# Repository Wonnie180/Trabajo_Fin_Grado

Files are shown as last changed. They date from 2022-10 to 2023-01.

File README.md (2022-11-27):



# Trabajo_Fin_Grado
Repositorio para el TFG UPNA (2022/2023)

# Requisitos Previos
## Hardware
### Para cada robot
- ESP32
- 2x Motores
- Batería
- 74HC595N
- L293D
  
###
## Software
## Windows
### Programas necesarios
- [Visual Studio Community 2019](https://visualstudio.microsoft.com/es/vs/older-downloads/)
- [Cuda ToolKit](https://developer.nvidia.com/cuda-toolkit)
- [CMake](https://cmake.org/download/)
- [Anaconda3](https://www.anaconda.com/products/distribution)
- [Código fuente de OpenCV](https://github.com/opencv/opencv)
- [Código fuente de OpenCV Contrib](https://github.com/opencv/opencv_contrib) (Misma versión que OpenCV)

### Configuraciones
#### Entorno Python
Modulos a instalar:
> pip install pybluez2 ndarray-listener-2.0.1 aioconsole

#### Compilar OpenCV con soporte para CUDA (GPU)
Importante:
Durante el tutorial se va a asumir que el directorio donde se va a trabajar es la siguiente:
>C:/Users/Usuario/Escritorio/OpenCV-GPU

1.  Crea una carpeta donde se almacenara el código fuente de OpenCV
Por Ejemplo: 
>C:/Users/Usuario/Escritorio/OpenCV-GPU

2.  Descomprime tanto el código fuente de OpenCV como OpenCV Contrib en dicha carpeta.
Deberían aparecer dos nuevas carpetas de forma que la estructura quede de la siguiente forma:
>C:/Users/Usuario/Escritorio/OpenCV-GPU/opencv-4.6.0\
>C:/Users/Usuario/Escritorio/OpenCV-GPU/opencv_contrib-4.6.0

3.  Crea una carpeta llamada build en el directorio de trabajo.
>C:/Users/Usuario/Escritorio/OpenCV-GPU

4.  Abre CMake
    1. En el apartado "Where is the source code:" introduce la carpeta donde se ha descomprimido el código fuente de OpenCV  
    > C:/Users/Usuario/Escritorio/OpenCV-GPU/opencv-4.6.0

    2. En el apartado "Where to build the binaries:", introduce la carpeta build creada en el paso anterior .
    >C:/Users/Usuario/Escritorio/OpenCV-GPU/build

    3. Dale al botón __Configure__
        1. En el primer apartado selecciona Visual Studio 17 2022
        2. En el segundo apartado selecciona x64
        3. Deja el resto como viene y dale a __Finish__

    4. Ahora busca las siguientes opciones y marcalas:
        * WITH_CUDA
        * ENABLE_FAST_MATH
        * BUILD_opencv_world
        * CUDA_FAST_MATH
    
    5. Busca __OPENCV_EXTRA_MODULES_PATH__ e introduce la carpeta modules que esta en la carpeta de OpenCV Contrib
    >C:/Users/Usuario/Escritorio/opencv_contrib-4.6.0/modules

    6. Vuelve a pinchar en __Configure__. Si no da ningún error, procede al siguiente punto.

    7. Ahora busca __CUDA_ARCH_BIN__. Aquí hay que seleccionar la Arquitectura de tu gráfica NVIDIA. Para ello tendrás que ir a la [Wikipedia](https://en.wikipedia.org/wiki/CUDA) y buscar tu gráfica. Tras encontrarla en la tabla, Introduce la versión de la primera columna (6.1 en el caso de una GTX 1080ti por ejemplo) en el parametro de CMake.     
    8. Busca el parametro __CMAKE_CONFIGURATION_TYPES__ y deja solo "Release".
    9. Por último, presiona el botón __Generate__.

5. A continuación, abre una ventana de linea de comandos (cmd o Powershell) y ejecuta el siguiente comando:
> & 'C:\Program Files\CMake\bin\cmake.exe' --build "C:/Users/Usuario/Escritorio/OpenCV-GPU/build" --target INSTALL --config Release

6. Cuando el proceso de compilación termine, en la misma terminal ejecuta __Python__ y ejecuta el siguiente código:
```
import cv2
cv2.cuda.getCudaEnabledDeviceCount()
```
&nbsp;&nbsp;&nbsp;&nbsp;&nbsp;&nbsp;
Si el resultado es un número mayor que 0, ya está todo listo para utilizar CUDA con OpenCV.  

#### Linux
TBD

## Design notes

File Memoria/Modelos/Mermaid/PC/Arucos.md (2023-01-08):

```mermaid
classDiagram
    %% -- Arucos
    IAruco <|-- Aruco
    Aruco <|-- Aruco_Drawable
    Runnable <|-- Aruco_Drawable
    Aruco_Drawable *-- IVideoSource 
    Aruco_Drawable *-- CV2ImShow_Drawable 

    IAruco: -int current_id
    IAruco: -any dictionary
    IAruco: -any detector_parameters
    IAruco: -any corners
    IAruco: -any ids
    IAruco: -any rejected

    IAruco: +Get_Current_Id() void
    IAruco: +Generate_new_Id(int size) any
    IAruco: +Detect_Aruco(Frame frame) void
    IAruco: +Get_Position_Of_Aruco(int id) any

    class Aruco{
       +Aruco(any dictionary, any detector_parameters) Aruco
    }

    class Aruco_Drawable{
        -IVideoSource video_source
        -CV2ImShow_Drawable video_playback
        -int frame_rate
        -int sleep_time

        +Aruco_Drawable(any dictionary, any detector_parameters, IVideoSource video_source, CV2ImShow_Drawable video_playback) Aruco_Drawable
        +Draw_Detected_Aruco() void
    }
```

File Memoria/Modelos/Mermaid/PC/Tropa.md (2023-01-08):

```mermaid
classDiagram
    %% -- Tropas
    ITropa <|-- Tropa
    ITropa <|-- FakeTropa
    ITropa *-- ICommunication
    ITropa *-- IPosition
    ITropa *-- Color
    
    ITropa: +int id
    ITropa: +ICommunication communication
    ITropa: +Color color
    ITropa: +IPosition position

    ITropa: +Move_Forward()
    ITropa: +Move_Backwards() void
    ITropa: +Turn_Left() void
    ITropa: +Turn_Right() void
    ITropa: +Set_Color(Color color) void
    class FakeTropa{
        -int time_delay
        -int[][][] matrix
        -int[][][] footprint
        +int degree_step
        +int distance_step

        +FakeTropa(int id, ICommunication communication, Color color, int[][][] matrix, int[][][] footprint, Position_2D position) FakeTropa
        -Do_Turn(int angle_direction, bool forward) void
        -Update_Matrix(int pos_x, int pos_y) void
        -Get_Movement_Parameters(int angle, int degree_of_movement) int[]
        -isValidFootPrint(int[][][] matrix, int[][][]footprint) bool
    }
    class Tropa{
        +Tropa(int id, ICommunication communication, Color color) Tropa
    }
```

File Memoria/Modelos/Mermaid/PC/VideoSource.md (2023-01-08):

```mermaid
classDiagram
    %% -- VideoSources
    IVideoSource <|-- FakeVideo
    IVideoSource <|-- WebCam
    
    IVideoSource: +bool has_new_frame
    IVideoSource: +Resolution resolution

    IVideoSource: +Get_Frame() Frame
    IVideoSource: +Get_FPS() int
    IVideoSource: +Set_FPS(int fps) void
    IVideoSource: +Get_Resolution() Resolution
    IVideoSource: +Set_Resolution(Resolution resolution) void
   
    class FakeVideo{
        -Frame frame

        +FakeVideo FakeVideo(Frame frame)
    }

    class WebCam{
        +WebCam(Resolution resolution, int number_webcam, int fps) WebCam
    }
   
```

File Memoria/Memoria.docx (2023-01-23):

E.T.S. de Ingeniería Industrial,
Informática y de Telecomunicación

Luis José Llamas Pérez

Asier Ruperto Marzo Pérez
Josu Irisarri Erviti

Pamplona, 19/01/2023

Mini Swarm Robots

Grado en Ingeniería Informática

Trabajo Fin de Grado

# Agradecimientos

A mis tutores, Asier Marzo y Josu Irisarri.

A mis compañeros de la carrera.

A Biko2 y 540.

A la Universidad Pública de Navarra

# Resumen

Este proyecto recoge el desarrollo de una inteligencia colectiva que pueda ser ampliable, de fácil implementación y bajo coste. El desarrollo de dicha inteligencia colectiva se divide en diferentes fases que abarcan tanto el diseño del robot y la inteligencia colectiva a nivel de hardware, como la implementación software de los mismos que permita los objetivos expuestos anteriormente.

A nivel de hardware se ha realizado el diseño e implementación de un chasis impreso en 3D, así como los circuitos electrónicos utilizados en los robots. Cabe destacar el uso de componentes fáciles de obtener tanto en el robot como en el sistema centralizado.

En lo que al Software se refiere, se ha realizado desde cero con la mentalidad de que pueda ser fácilmente ampliable y configurable. Esto se ha conseguido utilizando técnicas de diseño de software como la inyección de dependencias, Mocks y TDD (Desarrollo guiado por pruebas).

# Palabras clave

- Inteligencia colectiva
- Swarm robotics
- Robot
- ArUco
- TDD
- Inyección de Dependencias
- Mock

# Índice

# Introducción

A pesar de que la inteligencia colectiva no es algo nuevo, se ha trabajado poco en investigaciones para conseguir que sea de bajo coste y ampliable para cubrir diferentes necesidades.

Este proyecto surge para dar un primer paso que solucione esos inconvenientes con el fin de atraer la atención hacía el uso de la inteligencia colectiva como forma de resolver problemas.

# Justificación y Objetivos

El proyecto parte de la premisa de que la inteligencia colectiva no tiene que ser ni cara, ni complicada, fácilmente replicable y debe ser capaz de analizar y comunicarse con el entorno.

A raíz de la premisa anterior, surgen los siguientes objetivos:

- Los robots deben poder ser construidos con diferentes componentes, es decir, no tiene por qué haber dos robots iguales.
- Añadir un robot que use otro tipo de componentes no debe complicar el desarrollo ni alterar el funcionamiento de los que ya existen.
- El número de robots que puedan participar en la inteligencia colectiva ha de ser alto.
- Escalabilidad
- Los robots cumplirán una de las siguientes opciones:
  - Tener inteligencia propia y ser ellos mismo los responsables de la toma de decisiones
  - Tener un sistema centralizado que se encargue de dichas decisiones.
  - Ambas.
- El sistema de comunicación entre robots y/o el sistema centralizado tendrá que ser flexible, es decir, que se podrán utilizar diferentes tipos de sistemas de comunicación
- Los robots podrán tener comportamientos/patrones y actuar en base al entorno

Debido al amplio campo que es la inteligencia colectiva, no se van a poder abordar todos los objetivos iniciales en su totalidad, sin embargo, sí que se ha creado el camino para poder aumentar en funcionalidad y diseño de manera que en un futuro otra persona pueda continuar con el proyecto sin gran dificultad.

Para ello se han tomado una serie de decisiones que simplifican y a su vez acotan el alcance del proyecto. Estas decisiones se listan a continuación:

- Uso de material fácilmente adquirible por cualquier persona.
- Dicho material ha de ser de bajo coste.
- Software que sea fácilmente ampliable y modificable.
- Los robots serán controlados por un sistema centralizado.
- Solamente se usará un sistema comunicación entre los robots y el sistema centralizado.
- Se crearán dos robots con distintos componentes para la flexibilidad del proyecto.
- El control que ejerce el sistema centralizado será únicamente el movimiento de los robots de un punto a otro.

En los siguientes puntos se hablará sobre el hardware y software concreto que se ha decidido usar en el proyecto.

# Contexto tecnológico

La inteligencia colectiva es definida como el estudio del comportamiento colectivo cuando un sistema este compuesto de múltiples individuos que actúan en busca de un objetivo común. Esto permite abordar problemas de gran complejidad con individuos cuyas capacidades físicas/computacionales por separado sean inferiores a lo requerido.

Esto se consigue mediante el uso de comandos e interacciones simples que son elaboradas por un sistema central o individuos de mayor rango jerárquico.

# Metodología empleada

## ArUco

Para la detección y clasificación de los robots se van a utilizar marcadores ArUco, los cuales fueron diseñados por el grupo Ava de la Universidad de Córdoba (España) para proveer marcadores en tiempo real basándose en marcadores de Realidad Aumentada.

Estos marcadores se generan en base a un diccionario el cual tiene un tamaño predefinido de identificadores dependiendo del número de “bloques” que vaya a tener el marcador.

Estos marcadores tienen una característica muy importante y es que tienen orientación, por lo que podemos saber en todo momento el ángulo del robot.

Como detalle a tener en cuenta, estos marcadores tienen que tener un borde de otro color que no sea negro para funcionar correctamente.

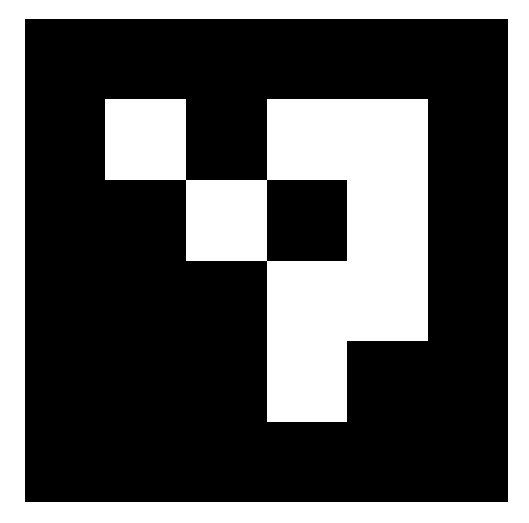
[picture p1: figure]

Figura 1: Marcador ArUco que representa el 0

Al ser un diseño muy simple y en blanco y negro, se puede binarizar la imagen antes de llegar a la fase de detección, lo cual hace que el coste computacional de detección y clasificación sea relativamente bajo, lo que convierte a este tipo de marcadores en una solución ideal para una aplicación como la que se propone en este proyecto.

## Mocks y TDD

La metodología empleada para el desarrollo del Software de este proyecto ha sido una modificación de TDD (Desarrollo guiado por pruebas) junto al uso de Mocks (Objetos simulados). Esto nos ha permitido comenzar a trabajar en el software sin conocer aún como va a ser el hardware, de esta forma, hemos conseguido desacoplar la dependencia del software y hardware.

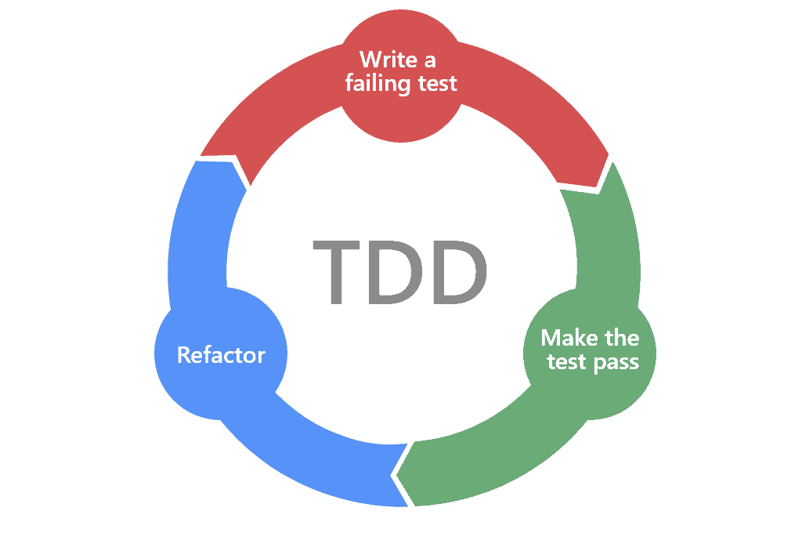
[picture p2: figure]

Figura 2: Diagrama de los estados en TDD (Rojo, Verde, Azul)

La manera en la que lo hemos logrado ha sido mediante la creación de Mocks de objetos que más adelante serán implementados de forma “real”.

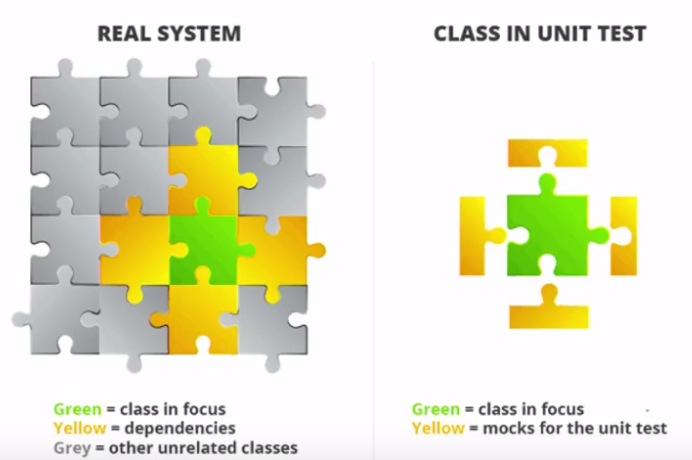
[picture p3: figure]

Figura 3: Ejemplo visual de Mocks

Usando la imagen de la Figura 3 como ejemplo, la parte en verde sería el sistema centralizado, mientras que las partes amarillas serían las dependencias del mismo, como, por ejemplo:

- Webcam (Para la obtención de posicionamiento de los robots).
- Sistema de comunicaciones (Para dar las órdenes a los robots).
- Robot (Para ejecutar las ordenes).

Si no hubiésemos usado Mocks, tendríamos que haber esperado a la implementación real de estos componentes antes de ponernos a trabajar en el sistema centralizado, ya que, no tendríamos feedback de si lo que estamos desarrollando es funcional o no.

Para solventar esto, se ha realizado un análisis previo de los componentes/actores necesarios por el sistema. Estos actores son candidatos a poder ser Mockeados, es decir, a crear una implementación “falsa” con las características y métodos que serán utilizados por la implementación real.

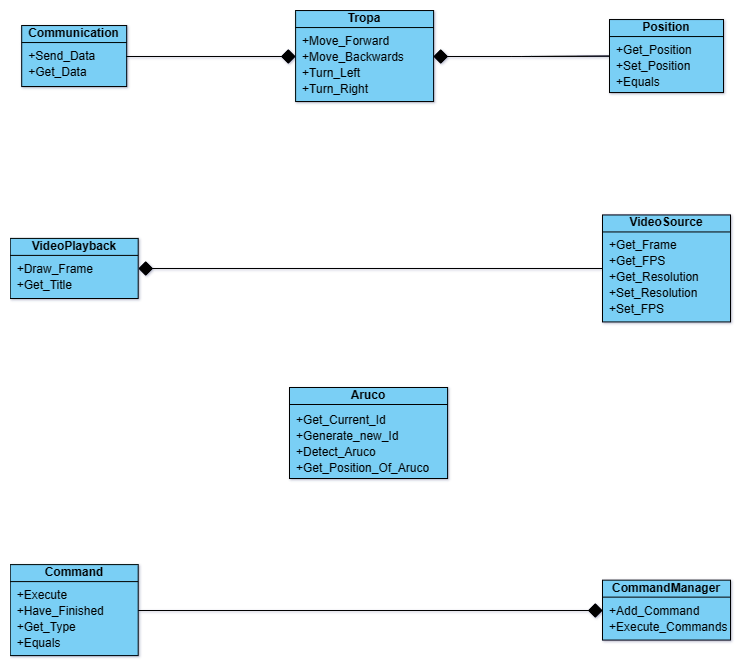
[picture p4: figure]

Figura 4: Actores del sistema centralizado

Los robots (Tropas) son un perfecto candidato a ser Mockeados, ya que nos permite desarrollar sin tener dicho robot. Esto genera un efecto mariposa, ya que, al no tener el robot, tampoco podemos obtener su posición usando una Webcam (VideoSource), por lo que el VideoSource también será mockeado. Lo mismo ocurre también con el sistema de comunicaciones (Communication).

El resto de componentes no tienen necesidad de ser Mockeados, al menos a primera vista, por lo que se puede proceder a la creación del sistema centralizado.

## Inyección de Dependencias

Dado que hemos realizado el análisis de los componentes y sus acciones/métodos, podemos enfocar el desarrollo de estos usando la inyección de dependencias, lo cual nos permitirá el desacople de las implementaciones finales consiguiendo así, un software fácilmente mantenible y actualizable.

El primer paso es crear interfaces en donde antes eran actores simples. Estas interfaces declararan los atributos y métodos/acciones del actor. A raíz de esta interfaz, se crearán las implementaciones finales, las cuales deben cumplir con el “contrato” (interfaz) que hereden.

Figura 5: Primer paso para la Inyección de Dependencias

En el ejemplo de la Figura 5 se ha creado la interfaz ITropa la cual tendrá una serie de métodos/acciones que tanto FakeTropa como Tropa deberán de implementar, cada uno a su manera.

Los Robots (Tropas) como hemos visto en la Figura 4, dependen del sistema de comunicaciones (Communication), por lo que estamos ante de una dependencia que podemos romper y hacerlo más flexible aplicando la simplificación de la Figura 4 al actor Communication.

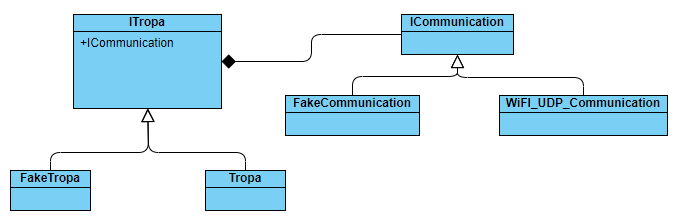
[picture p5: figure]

Figura 6: Inyección del sistema de comunicaciones como dependencia

Como podemos observar en la Figura 6, las Tropas ya no dependen de la implementación concreta del sistema de comunicaciones, si no que podemos mezclar, por ejemplo, el uso de una Tropa falsa y un sistema de comunicaciones basado en UDP por WiFi. Esto es lo que nos va a permitir añadir en un futuro de forma sencilla implementaciones concretas (ya sean reales o Mocks) sin tener que modificar el código que ya existía previamente.

Tras realizar este ejercicio sobre el resto de los actores del Sistema Centralizado, obtenemos el diagrama de clases de la Figura 7.

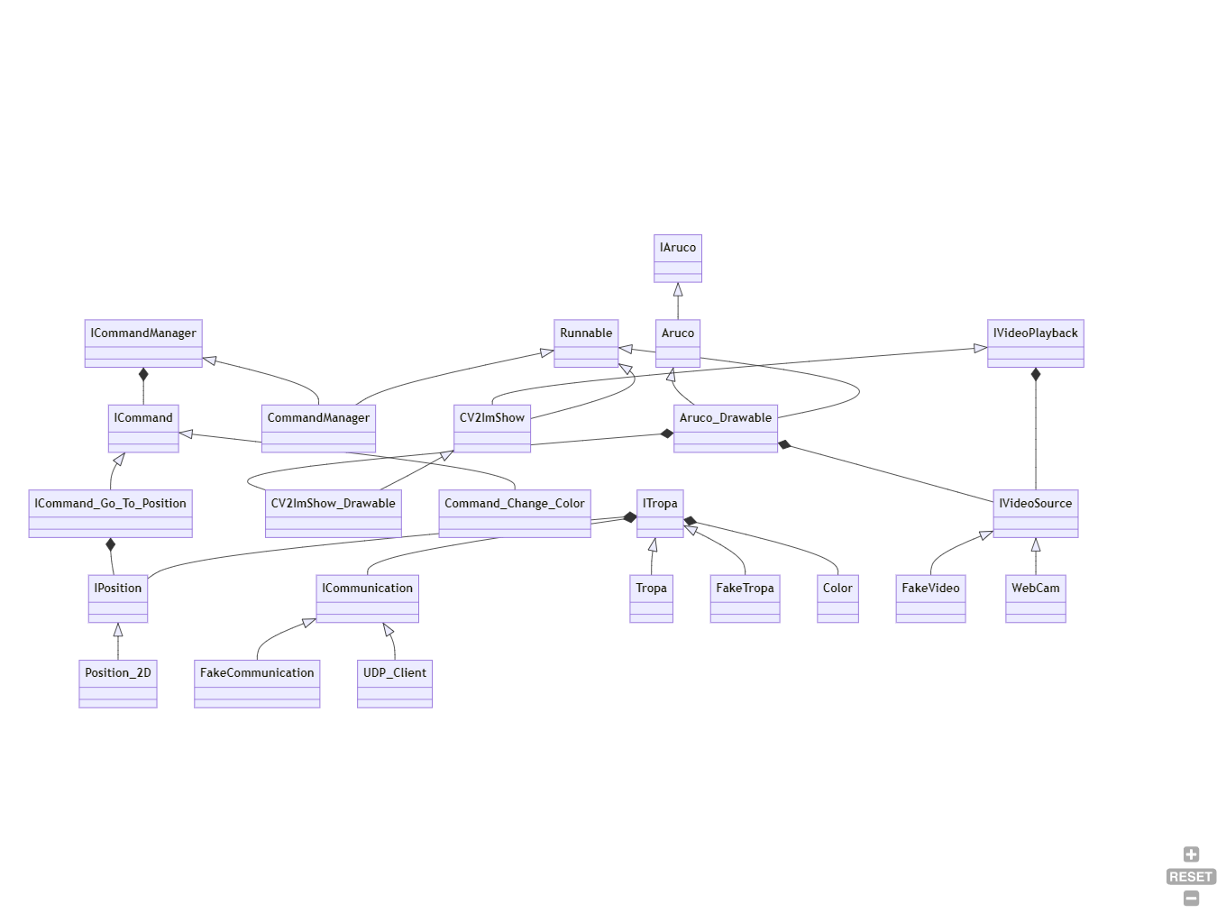
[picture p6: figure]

Figura 7: Diagrama de clases del Sistema Centralizado

Tal y como hemos visto en el sistema centralizado, también se pueden aplicar estas técnicas a la hora de la programación de los robots, donde la abstracción será en los componentes del Robot (Motor, Led, Sistema de Comunicación).

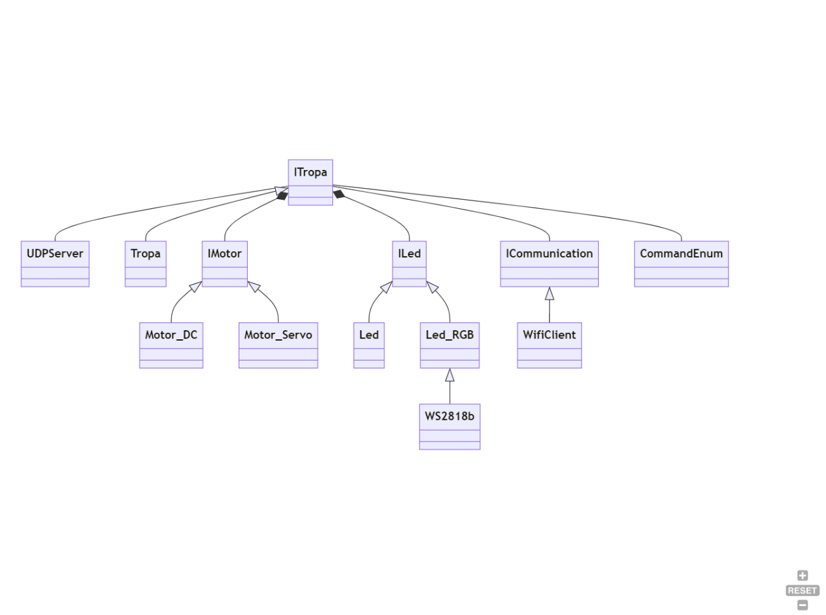
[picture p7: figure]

Figura 8: Diagrama de clases del Robot

Una vez se ha creado el software, pasar al hardware es trivial, ya que, se utilizan componentes fácilmente obtenibles, donde la única preocupación es la “conexión” entre ellos, como por ejemplo el control de los motores.

# Mini Swarm Robots

## Hardware

El hardware como se ha explicado anteriormente, es de bajo coste y accesible. En líneas generales hay dos grandes separaciones, el hardware de los robots y el del sistema centralizado.

### Robots

En el caso de los robots, lo más importante para cumplir los objetivos, es el movimiento. En este caso se ha decidido usar un sistema de dos ruedas motorizadas encargadas de la tracción y una rueda “loca”.

Las ruedas motorizadas como su nombre indica, consisten en dos motores que al girar a distintas velocidades consiguen el movimiento y giro del robot. Para controlar dichos motores, se utiliza un microcontrolador que será el cerebro del robot y para alimentar el robot, un Powerbank de 5V y 1000mAh. Todo esto va integrado en un cuerpo impreso en 3D que permita que todos los componentes tengan un balance de peso optimo.

#### Microcontrolador

El microcontrolador que se ha utilizado es un ESP32 WROOM-32, el cual viene equipado con WiFi y Bluetooth.

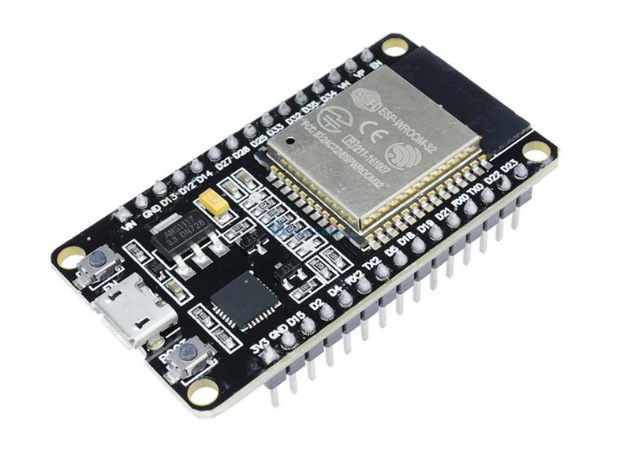
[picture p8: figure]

Figura 9: ESP32 WROOM-32

Este microcontrolador es más que suficiente para el proyecto y su elección radica en el hecho de que tiene un precio asequible, es fácil de obtener y tiene una gran cantidad de puertos de entrada/salida, así como comunicaciones WiFi y Bluetooth incluidas.


Figura 10: Pinout del ESP32 WROOM-32

Como características importantes, el microcontrolador cuenta con un regulador de voltaje que permite ser alimentado desde 12V hasta 3.3V. Cabe destacar que el voltaje al que opera este dispositivo es de 3.3V, por lo que puede dar problemas con circuitos integrados cuyo umbral de activación sea superior a dicho voltaje. Esto puede remediarse con un transistor que actúe de Step-Up usando un pin de entrada/salida (GPIO) del microcontrolador.

Otra característica de este microcontrolador es la posibilidad de utilizar un sistema de comunicaciones propio basado en WiFi llamado ESP-MESH, el cual puede ser interesante de cara a aumentar tanto el número de robots, como la distancia entre estos y el sistema centralizado.

#### Motores

Los motores utilizados en los robots que se han prototipado son motores DC simples con una caja reductora y motores Servo modificados para permitir el giro completo.

#### Motor DC

Para el caso de los motores DC simples se ha utilizado el circuito integrado L293D para controlar hasta dos motores por circuito. Este circuito integrado permite controlar tanto el sentido de giro de los motores, como su velocidad.

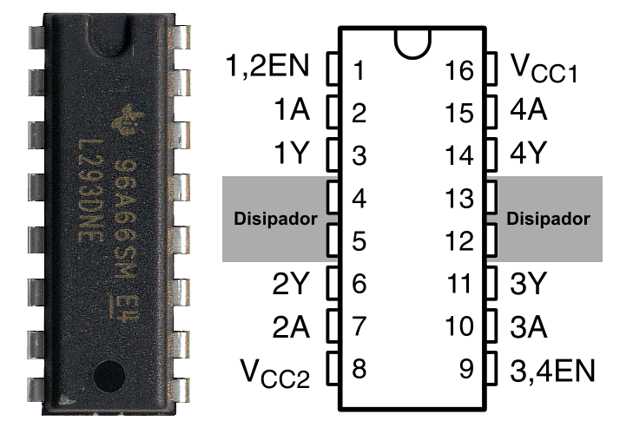
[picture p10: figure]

Figura 11: Pinout del IC L293D

Para obtener un movimiento más controlado se va a hacer uso de un sistema de engranajes que actúe de reductora. De esta forma, el movimiento del motor pasa a estar algo más controlado que si se dejase sin dicha reductora..

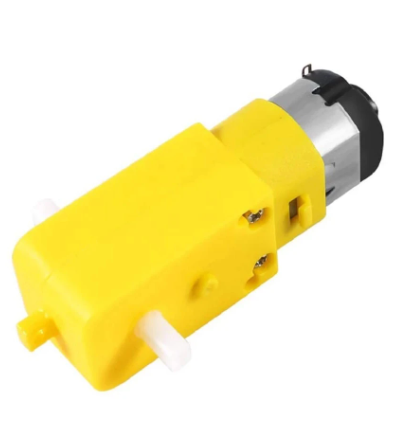
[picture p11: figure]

Figura 12: Sistema de engranajes reductor

#### Motor Servo

En el caso de los motores Servo, no se necesita el uso de ICs ya que, estos incluyen su propio controlador, así como un sistema de engranajes que actúa de reductora. La desventaja es que hay que modificar cada motor servo para permitir el movimiento continuo. Como ventaja, basta con conectar un único pin al microcontrolador por cada motor, mientras que en el caso del L293D, hay que conectar dos pines por cada motor.

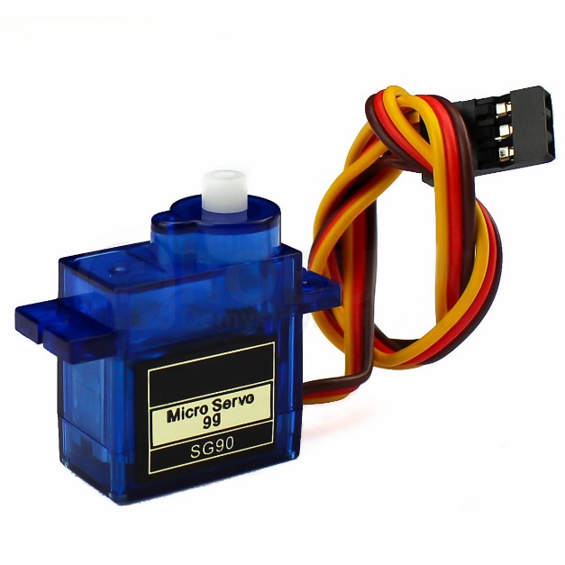
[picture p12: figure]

Figura 13: Motor Servo

El proceso de modificación de un motor servo para permitir el giro continuo consta de cinco pasos:

1. Desarmar el servo.
2. Eliminar el limitador físico del sistema de engranajes.
3. Mover fuera el potenciómetro que se encarga de determinar la posición del servo.
4. Volver a armar el servo.
5. Calibrar el potenciómetro de forma que el servo piense que está siempre en el punto medio (90 grados).

Tras esta modificación, se tiene un control de dirección (por debajo del punto medio girará en un sentido, mientras que, por encima de dicho punto, girará en el sentido contrario) y de velocidad (conforme más nos alejemos del punto medio, a más velocidad girará el motor).

#### Chasis

El chasis empleado se ha diseñado para los componentes específicos que se han usado en los robots. Es un prototipo simple que se puede imprimir rápidamente y que tiene en cuenta el equilibrio de los pesos de los componentes para tratar de conseguir un movimiento menos errático.

El chasis se ha diseñado utilizando la herramienta Autodesk Fusion 360 y se ha impreso en una impresora Prusa MK3 utilizando PrusaSlicer para convertir del formato STL a GCODE.

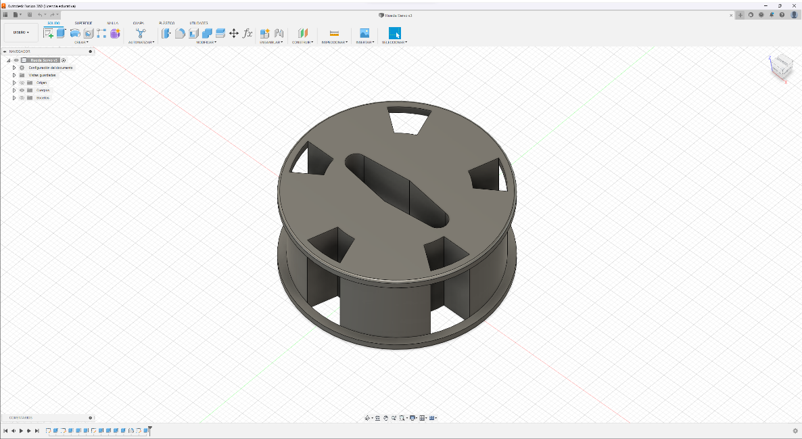
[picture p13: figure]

Figura 14: Diseño de las ruedas en Autodesk Fusion 360

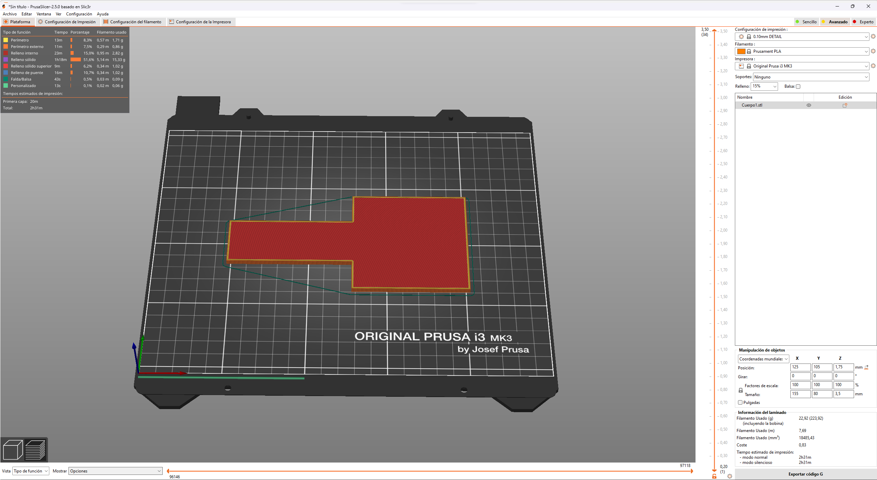
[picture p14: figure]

Figura 15: PrusaSlicer

### Circuitos

La Figura 14 muestra como se ha realizado el conexionado del robot en el caso de los motores DC.

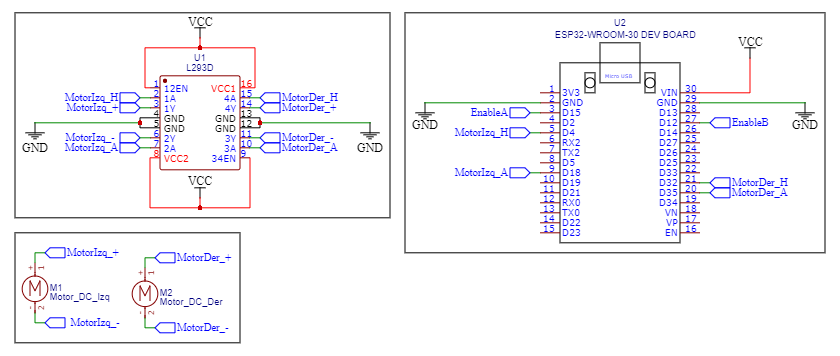
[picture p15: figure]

Figura 16: Circuito del Robot con motores DC

### Sistema centralizado

El hardware del sistema centralizado se compone de las siguientes partes:

- PC donde ejecutar el código
- Webcam que irá conectada al PC
- Red WiFi (para el caso concreto que hemos implementado)

Los requisitos mínimos del PC son el poder ejecutar Python 3.9, al menos cuatro núcleos/hilos y 4 GB de RAM.

No se especifica arquitectura ya que, es válido tanto en un sistema convencional x86/x64 como en ARM64 (aarch64).

El requisito de los cuatro núcleos/hilos viene debido a la utilización de multihilo para mejorar el rendimiento del código. Esto viene explicado con detalle en el apartado de Software.

### Presupuesto

Ya que se ha hecho hincapié en que el proyecto sea accesible y barato, a continuación, se recoge una lista de los materiales necesarios para la recreación del proyecto junto a su precio (*).

Robot con motores DC

Componente | Cantidad | Precio unitario | Total
ESP32-WROOM (https://es.aliexpress.com/item/1005002410521023.html?curPageLogUid=b8SKd9ntGUEf) | 1 | 3.57€ | 3.57€
IC L293D (https://es.aliexpress.com/item/32844099228.html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) | 1 | 0.22€ | 0.22€
Motor DC (https://es.aliexpress.com/item/1005002264331819.html?curPageLogUid=qrvC43PMpnFg) | 2 | 0.73€ | 1.46€
Powerbank (https://es.aliexpress.com/item/1005004227379153.html?curPageLogUid=xNM8dMRF95fI) | 1 | 1.29€ | 1.29€
Chasis impresión 3D | 1 | 1.00€ | 1.00€
Total | 7.54€

Tabla 1: Presupuesto del Robot con motores DC

Robot con motores servo

Componente | Cantidad | Precio unitario | Total
ESP32-WROOM (https://es.aliexpress.com/item/1005002410521023.html?curPageLogUid=b8SKd9ntGUEf) | 1 | 3.57€ | 3.57€
Motor Servo (https://es.aliexpress.com/item/32944897962.html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) | 2 | 1.48€ | 2.96€
Powerbank (https://es.aliexpress.com/item/1005004227379153.html?curPageLogUid=xNM8dMRF95fI) | 1 | 1.29€ | 1.29€
Chasis impresión 3D | 1 | 1.00€ | 1.00€
Rueda impresión 3D | 2 | 1.09€ | 2.18€
Total | 12.00€

Tabla 2: Presupuesto del Robot con motores servo

*: Estos precios se han obtenido de Aliexpress en el momento de su redacción, por lo que pueden estar sujetos a cambios.

### Resultados

Los resultados de esta implementación Hardware pueden ser vistos en la Figura 17.

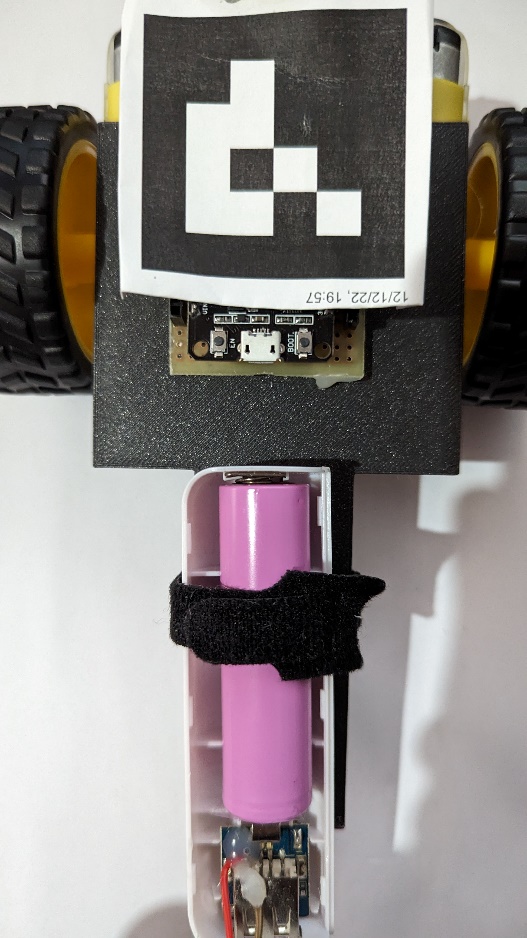
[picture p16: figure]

Figura 17: Prototipo del Robot con motores DC

## Software

Como ya se ha explicado en el apartado de Metodología empleada, el Software se ha enfocado en el uso de TDD e Inyección de Dependencias.

En este apartado se va a mostrar en más detalle cómo se ha construido el Software tanto para los robots, como para el sistema centralizado.

### Robots

La parte de los robots es la más sencilla debido a que se trata de una implementación ligada al Hardware en la que solamente hay que hacer el Software que sirva de intermediario entre el Hardware y el sistema centralizado.

Dado que ya se ha realizado el diagrama de clases de los robots en la Figura 8 y lo sencillo del software de los robots, se va a pasar al sistema centralizado.

### Sistema Centralizado

El sistema centralizado es la parte más importante en cuanto a Software se refiere, ya que, es la parte encargada de gestionar las acciones/comportamientos, así como detección de los individuos.

La explicación se va a organizar en apartados donde se explicarán los elementos más relevantes de cada actor. También se van a dedicar apartados al movimiento, al multihilo y al simulador.

#### Tropas

En el caso de las Tropas, no hay nada destacable, ya que, las acciones de estas son realmente enviar la acción usando el sistema de comunicaciones al robot real.

Las acciones que se han definido son las siguientes:

1. Moverse hacía adelante
2. Moverse hacía atrás
3. Girar a la izquierda
4. Girar a la derecha
5. Cambiar el color del led

De estas acciones la única que debe llevar algo más de información a parte de la acción en sí, es el cambio de color. Por lo que se ha decidido que el sistema de comunicaciones va a enviar siempre primero la acción seguido en caso de ser necesario, de un valor/valores que acompañe/en a la acción.

Para ahorrar en tiempo y espacio, dichas acciones van a ser codificadas usando un Enum que será común tanto en la clase de la Tropa del sistema centralizado como en el robot.

#### ArUco

Se ha decidido usar la implementación de los marcadores ArUco que viene en OpenCV, esto permite desde la creación de los diccionarios de los marcadores hasta la detección y clasificación de los marcadores junto a sus coordenadas.

#### VideoSource y VideoPlayback

Para la entrada de video se ha decidido usar la librería de OpenCV la cual tiene ya implementados los métodos que necesitamos para el sistema central. Además, se ha creado un Mock que simula un frame con el fin de poder simular la entrada de video.

En el caso de la salida de video, usamos nuevamente la librería de OpenCV para mostrar los frames que vamos obteniendo desde la entrada de video.

Aprovechando la funcionalidad que da OpenCV, la salida de video puede dibujar por encima del frame formas simples (líneas, rectángulos, círculos y texto).

#### CommandManager y Command

Para facilitar la gestión de las acciones de los robots, se ha creado un gestor de comandos y los comandos. El gestor de comandos gestiona los comandos mediante una lista de estos. Se organiza utilizando el método FIFO (First In First Out) donde se ejecutarán a la vez todos los comandos que no vayan dirigidos a la misma Tropa y sean del mismo tipo.

Tropa | Tipo Comando | Estado
0 | Go_To_Position | Ejecutando
0 | Go_To_Position | En Espera
0 | Go_To_Position | En Espera
0 | Cambiar_Color | Ejecutando
1 | Go_To_Position | Ejecutando

Tabla 2: Ejemplo de la cola FIFO del CommandManager

Los comandos que se han creado se dividen en dos categorías, el de ir a una posición y cambiar de color.

#### Movimiento

Uno de los problemas que nos encontramos al comenzar con este proyecto es la toma de decisión sobre qué movimiento deberá hacer el robot para llegar a su destino. En el caso que se ha planteado en el proyecto, el mundo tiene dos dimensiones, conocemos tanto las coordenadas del punto al que queremos ir, como la posición y orientación del robot (esto último gracias a los marcadores ArUco).

Con estos datos podemos aplicar un algoritmo determinista que haga lo siguiente:

1. Obtener la posición destino
2. Obtener la posición y orientación actual
3. Comprobar si el robot tiene enfrente o a su espalda el destino
4. Si lo tiene, avanzar hacía el en línea recta bien moviéndose hacía adelante o hacía atrás.
5. Si no lo tiene, girar a la izquierda o derecha dependiendo de que giro le vaya a costar menos hasta tenerlo de frente.

Lo complicado de este algoritmo es el cálculo de las orientaciones, así como el ajuste del umbral para cambiar la acción. Este umbral es el que va a evitar que podamos caer en bucles infinitos debido al movimiento no preciso del robot.

Para calcular primero la orientación del robot respecto al Frame, se ejecuta la siguiente formula:

Orientación del Robot=(360-((atan2(x_(Centro) -x_(Frente) ,-(y_(Centro) -y_(Frente) ) ))*180/π))

El cálculo de las posiciones (x, y) tanto del centro como del frente del robot es trivial, ya que, el marcador ArUco devuelve las posiciones de las cuatro esquinas ordenadas.

El cálculo del Angulo que hay entre el robot y el punto se calcula de esta forma:

Angulo Robot-Destino=(360-((atan2(x_(Objetivo) -x_(Real) ,-(y_(Objetivo) -y_(Real) ) ))*180/π))

A los resultados hay que llevárselos al rango de 0 – 360 y sustraerles 90 para compensar el cambio de plano que efectúa OpenCV en las imágenes.

A continuación, se va a explicar con un ejemplo el proceso del algoritmo de movimiento de los robots.

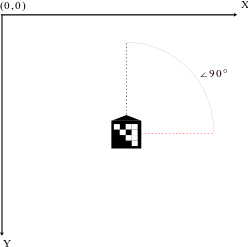
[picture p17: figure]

Figura 18: Primer paso de la explicación del movimiento de los robots

En la Figura 18 se puede ver al robot quieto sin ningún objetivo. Utilizando la fórmula para calcular la orientación del robot, obtenemos que está mirando a 90 grados.

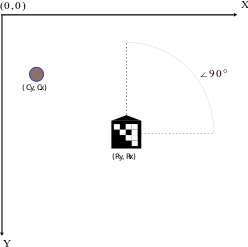
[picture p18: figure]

Figura 19: Segundo paso de la explicación del movimiento de los robots

Ahora se le ha generado un destino al robot, el cual es un punto que se encuentra en las coordenadas (Cx, Cy) y el robot está en (Rx, Ry).

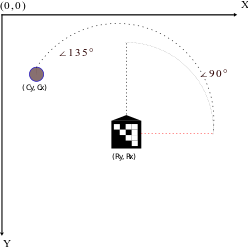
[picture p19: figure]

Figura 20: Tercer paso de la explicación del movimiento de los robots

Utilizando la fórmula para calcular el Angulo que forman el robot con el destino, obtenemos que el punto está a 135 grado. Eso significa que la diferencia entre los ángulos es de 135-90 = 45. Suponiendo que el robot previamente se estuviese moviendo hacía adelante y que el umbral para él cambio de acción sea igual o inferior a 45, el robot se girara en sentido antihorario para tratar de posicionarse en frente del destino.

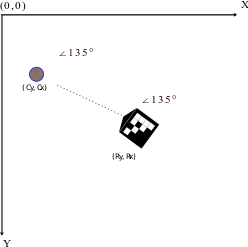
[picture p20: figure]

Figura 21: Cuarto paso de la explicación del movimiento de los robots

El robot ha girado a la izquierda (sentido antihorario) hasta posicionarse enfrente del objetivo.

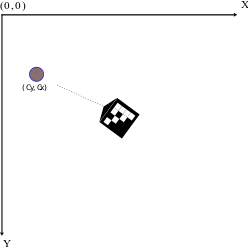
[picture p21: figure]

Figura 22: Quinto paso de la explicación del movimiento de los robots

Como el ángulo que forman el punto con el frente del robot es 0, esté avanza hacía el punto.

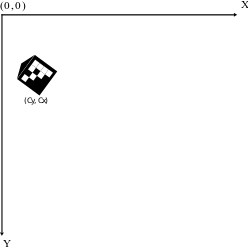
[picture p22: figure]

Figura 23: Último paso de la explicación

Por último, una vez que el robot llega al destino, el comando se deja de ejecutar y el robot se para.

#### Multihilo

Dada la naturaleza del proyecto, el coste computacional puede crecer rápidamente. Sin embargo, hay varias formas de afrontar este problema, una de ellas es el multihilo.

Como se puede observar en la Figura 4, hay cuatro grupos de “actores” en el sistema. Esto significa que podemos llegar a trabajar de forma separada en cuatro hilos diferentes, ya que, ninguno de los grupos depende fuertemente de otro.

De los cuatro grupos que hay uno de ellos no tiene sentido paralelizarlo, ya que, no interviene directamente en el sistema. Este grupo son las Tropas (robots), las cuales solamente envían comandos y no tienen coste computacional per se.

Los otros tres grupos pueden ser paralelizados, aunque realmente trabajen de manera secuencial. El flujo del programa es el que aparece en la Figura 24.

En dicho diagrama podemos observar cómo existe un tiempo de procesamiento en el actor Aruco, el cual no interacciona con VideoPlayback, por lo que al ejecutar en paralelo estos dos obtenemos un sistema más responsive.

Por otro lado, está el CommandManager, el cual hemos visto que no depende de ninguno de los actores del sistema.

El resultado final es que el sistema centralizado va a utilizar cuatro hilos, el principal, uno para el VideoPlayback, otro para Aruco y el ultimo será utilizado por el CommandManager

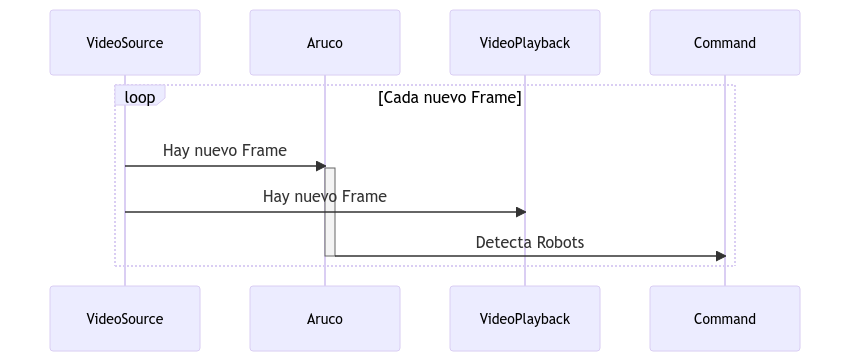
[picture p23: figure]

Figura 24: Diagrama de secuencia del funcionamiento del sistema central

#### Simulador

El simulador no es más que el uso de Mocks para simular las Tropas y el VideoSource. Para ello se han creado las siguientes implementaciones:

- FakeTropa
- FakeVideo
- FakeCommunication
- Command_Go_To_2D_Position_Fake

La forma de simular que se ha implementado consiste en generar una matriz que simulará el Frame de la WebCam.

Las Tropas serán matrices que se pintan de forma programática y el movimiento de las tropas será el resultado de mover las matrices dentro del Frame simulado. Como se ha visto en el apartado de Movimiento, las FakeTropas tendrán un umbral de 90 grados debido a la naturaleza del Frame.

Esto da lugar al resultado de la Figura 25.

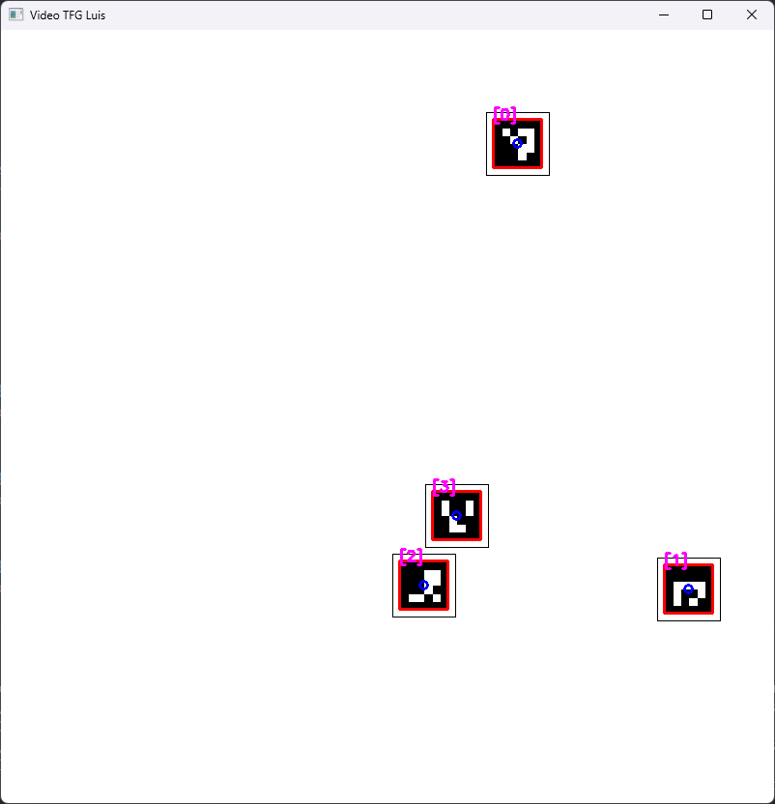
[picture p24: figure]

Figura 25: Simulador de Tropas

Gracias al simulador se ha podido desarrollar y depurar de forma más eficaz el proyecto. Alguna de las limitaciones del simulador son las siguientes:

- Rango de giro de las Tropas simuladas limitado a 90 grados
- Movimiento exacto
- Coste computacional

## Líneas futuras

Debido a la naturaleza del proyecto, los caminos por los que continuar son muy variados, pero se pueden definir en dos grandes categorías, Software y Hardware.

Dentro del apartado Software aparecen las siguientes propuestas:

- Creación de comandos que aporten nuevos comportamientos, como, por ejemplo, que todos los robots se reúnan en un punto
- Espacio de configuraciones para hacer más preciso el movimiento del robot
- Algoritmo de Path Finding que permita a los robots esquivar obstáculos
- Mapeado dinámico de la zona de forma que los robots sean capaces de recordar que caminos han ido tomando
- Simulador en Unity u otro motor para mejorar las capacidades de depuración e implementación del proyecto.
- Añadir de manera dinámica nuevos robots según vayan apareciendo en el plano y eliminarlos cuando salgan del mismo (posibilidad de encadenar varias cámaras una detrás de otra)

Por su parte, dentro del Hardware se propone continuar con las siguientes:

- Minimizar el tamaño del robot
- Pasar de un robot que se mueve en 2D a uno que se mueva en 3D
- Mejorar el consumo del robot
- Explorar otras formas de alimentación (energía solar, por ejemplo)
- Explorar otras formas de posicionamiento (odometría, uso de balizas, etc.)
- Pasar a una arquitectura jerárquica
- Pasar a una arquitectura descentralizada
- Pasar a una arquitectura hibrida

# Bibliografía y referencias

https://docs.opencv.org/4.x/

https://docs.opencv.org/4.x/d5/dae/tutorial_aruco_detection.html

https://docs.opencv.org/4.x/db/deb/tutorial_display_image.html

https://es.wikipedia.org/wiki/Inteligencia_colectiva

https://github.com/Wonnie180/Trabajo_Fin_Grado

# Anexos

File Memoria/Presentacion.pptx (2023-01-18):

## Mini Swarm robots

Grado en Ingeniería Informática
Trabajo Fin de Grado

Luis José Llamas Pérez
Asier Ruperto Marzo Pérez
Josu Irisarri Erviti

Pamplona, 19/01/2023

## Contenido

1. Introducción
2. Objetivos
3. Software
4. Hardware
5. Conclusiones
6. Líneas futuras
7. Demo

## Introducción

## Introducción

- ¿Qué es la inteligencia colectiva?
- ¿Qué tipos de implementación hay?
- ¿Qué ventajas ofrece?
- ¿Qué problemas tiene?
- ¿Qué soluciones podemos dar a esos problemas?

## ¿Qué es la inteligencia colectiva?

“Collective intelligence is a form of universally distributed intelligence, constantly enhanced, coordinated in real time, and resulting in the effective mobilization of skills”
“La inteligencia colectiva es una forma de inteligencia distribuida universalmente, constantemente mejorada, coordinada en tiempo real, y que resulta en la movilización efectiva de habilidades.”
Pierre Lévy “Collective Intelligence: Mankind’s Emerging World in Cyberspace” (1994)

## ¿Qué tipos de implementación hay?

- Arquitectura centralizada
  - Un único sistema de control que toma las decisiones y da las ordenes.
  - Robots simplemente acatan las ordenes.
- Arquitectura jerárquica
  - Varios sistemas de control con distintos niveles de jerarquía.
  - Distintas decisiones y ordenes según el nivel de jerarquía.
- Arquitectura descentralizada
  - No existe el concepto de sistema de control.
  - Los robots toman decisiones basándose en su entorno y la información transmitida entre ellos.
- Arquitectura hibrida
  - Existe un sistema de control que supervisa los robots y da ordenes puntuales.
  - Los robots se comportan como en la arquitectura descentralizada.

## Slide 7

- ¿Qué ventajas ofrece?

- Diseño escalable
- Flexibilidad a la hora de resolver problemas
- Redundancia
- Posibilidad de cubrir grandes áreas

- ¿Qué problemas tiene?

- Difícil de implementar
- Muchas variables a tener en cuenta
- Coste
- Difícil de replicar

## ¿Qué soluciones podemos dar a esos problemas

- Implementación
  - Diseño de software con la ampliación siempre presente
- Muchas variables a tener en cuenta
  - Enfocarse en un problema para generar una única solución
- Coste
  - Utilización de componentes baratos y fáciles de obtener
- Difícil de replicar
  - Crear un framework que utilice tecnologías abiertas

## Objetivos

## Objetivos

- Uso de material fácilmente adquirible por cualquier persona.
- Dicho material ha de ser de bajo coste.
- Software que sea fácilmente ampliable y modificable.
- Los robots serán controlados por un sistema centralizado.
- Solamente se usará un sistema comunicación entre los robots y el sistema centralizado.
- Se crearán dos robots con distintos componentes para la flexibilidad del proyecto.
- El control que ejerce el sistema centralizado será únicamente el movimiento de los robots de un punto a otro.

## Software

## Software

- TDD (Desarrollo guiado por pruebas)
- Inyección de dependencias
- Diagramas de clases
  - Sistema centralizado
  - Robots
- Movimiento
- Multihilo
- Simulador

## TDD (Desarrollo guiado por pruebas)


## Inyección de Dependencias


## Inyección de Dependencias


## Inyección de Dependencias


## Diagrama de clases del Sistema Centralizado


## Diagrama de clases del Robot


## Movimiento


## Movimiento


## Movimiento


## Movimiento


## Movimiento


## Movimiento


## Multihilo


## Simulador


## Hardware

## Hardware

- Microcontrolador
  - ESP32 WROOM
- Motores
  - Corriente continua (CC / DC)
  - Servos (modificados para permitir rotación completa)
- Circuitos integrados
  - L293D para controlar los motores DC
- Impresión 3D
  - Creación del chasis
  - Creación de las ruedas
- Alimentación
  - Batería powerbank 5V

## Microcontrolador


## Motores / ICs

Motor DC


Motor Servo


## Impresión 3D


## Conclusiones

## Conclusiones

- Proyecto muy versátil
- Muchas utilidades
  - Equipos de rescate
  - Trabajos en zonas donde el ser humano no puede llegar (mar)
- Objetivos cumplidos
- Mejorable

## Líneas futuras

## Líneas futuras

- Software
  - Espacio de configuraciones para hacer más preciso el movimiento del robot
  - Algoritmo de Path Finding que permita a los robots esquivar obstáculos
  - Mapeado dinámico de la zona de forma que los robots sean capaces de recordar que caminos han ido tomando
  - Simulador en Unity u otro motor para mejorar las capacidades de depuración e implementación del proyecto.
- Hardware
  - Minimizar el tamaño del robot
  - Pasar de un robot que se mueve en 2D a uno que se mueva en 3D
  - Mejorar el consumo del robot
  - Explorar otras formas de alimentación (energía solar, por ejemplo)
  - Pasar a una arquitectura jerárquica

## Demo

## Setup


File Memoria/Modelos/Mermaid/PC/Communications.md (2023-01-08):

```mermaid
classDiagram
    %% -- Communications
    ICommunication <|-- FakeCommunication
    ICommunication <|-- UDP_Client

    ICommunication: +Send_Data(int action, int[] data) void
    ICommunication: +Get_Data() string
   
    class FakeCommunication{
        +FakeCommunication() FakeCommunication
    }

    class UDP_Client {
        -string ip_address
        -int port
        -void socket

        +UDP_Client(string ip_address, int port) UDP_Client
    }
```

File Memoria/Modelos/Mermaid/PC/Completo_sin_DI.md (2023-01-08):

```mermaid
classDiagram
    Tropa *-- Communication
    Tropa *-- Position

    VideoPlayback *-- VideoSource

    CommandManager *-- Command

    class Aruco {
        -int current_id
        -any dictionary
        -any detector_parameters
        -any corners
        -any ids
        -any rejected

        +Get_Current_id() void
        +Generate_new_id(int size) any
        +Detect_Aruco(Frame frame) void
        +Get_Position_Of_Aruco(int id) any
    }

    class Communication {
        +Send_Data(int action, int[] data) void
        +Get_Data() string
    }

    class Command {
        +Execute() void
        +Have_Finished() bool
        +Get_Type() string
        +Equal(Command command) bool
    }

    class CommandManager {
        +Add_Command(ICommand command) void
        +Execute_Commands() void
    }

    class Position {
        +Get_Position() int[]
        +Set_Position(int[] new_position) void
        +Equals(int[] position, int offset) bool
        -Check_Position_Length() bool
    }

    class Tropa {
        +int id
        +Communication communication
        +Color color
        +Position position

        +Move_Forward()
        +Move_Backwards() void
        +Turn_Left() void
        +Turn_Right() void
        +Set_Color(Color color) void
    }

    class VideoPlayback {
        +bool has_to_stop
        +VideoSource videoSource
        +string title

        +void Draw_Frame()
        +void Get_Title()
    }

    class VideoSource {
        +bool has_new_frame
        +Resolution resolution

        +Get_Frame() Frame
        +Get_FPS() int
        +Set_FPS(int fps) void
        +Get_Resolution() Resolution
        +Set_Resolution(Resolution resolution) void        
    }
```

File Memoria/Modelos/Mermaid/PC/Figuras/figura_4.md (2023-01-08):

```mermaid
classDiagram
    %% -- Tropas
    ITropa *-- Communication
    ITropa *-- Position    
    ITropa <|-- FakeTropa
    ITropa <|-- Tropa
    ITropa *-- Color

    class ITropa{
        <<Interface>>
        +int id
        +Communication communication
        +Color color
        +Position position

        +Move_Forward()
        +Move_Backwards() void
        +Turn_Left() void
        +Turn_Right() void
        +Set_Color(Color color) void
    }
   
    class Tropa{
        +Tropa(int id, ICommunication communication, Color color) Tropa
    }
    
    class FakeTropa{
        -int time_delay
        -int[][][] matrix
        -int[][][] footprint
        +int degree_step
        +int distance_step

        +FakeTropa(int id, ICommunication communication, Color color, int[][][] matrix, int[][][] footprint, Position position) FakeTropa
        -Do_Turn(int angle_direction, bool forward) void
        -Update_Matrix(int pos_x, int pos_y) void
        -Get_Movement_Parameters(int angle, int degree_of_movement) int[]
        -isValidFootPrint(int[][][] matrix, int[][][]footprint) bool
    }

    class Communication {
        <<Interface>>
    }

    class Position {
        <<Interface>>
    }
    
```

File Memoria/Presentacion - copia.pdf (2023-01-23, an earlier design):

# MINI SWARM ROBOTS

Grado en Ingeniería Informática Trabajo Fin de Grado

Autor: Luis José Llamas Pérez

Director: Asier Ruperto Marzo Pérez
Co-Director: Josu Irisarri Erviti ¹ | Pamplona, 19/01/2023

# ¿Qué es la inteligencia colectiva?

“Collective intelligence is a form of universally distributed intelligence, constantly enhanced, coordinated in real time, and resulting in the effective mobilization of skills”

Pierre Lévy “Collective Intelligence: Mankind’s Emerging World in Cyberspace” (1994)

### “La inteligencia colectiva es una forma de inteligencia distribuida universalmente, constantemente mejorada, coordinada en tiempo real, y que resulta en la movilización efectiva de habilidades.”

# ¿Qué tipos de implementación hay?


Centralizada | Jerárquica
Descentralizada | Híbrida


## ¿Qué ventajas ofrece?

## ■ Diseño escalable

## ■ Flexibilidad

## ■ Redundancia

## ■ Cubrir grandes áreas

## ¿Qué problemas tiene?

## ■ Difícil de implementar

## ■ Muchas variables

## ■ Coste

## ■ Difícil de replicar

# La inteligencia colectiva…

## ¿Qué problemas tiene?

## ■ Difícil de implementar

## ■ Muchas variables

## ■ Coste

## ■ Difícil de replicar

# ¿Cómo podemos solucionarlo?

## Solución

## ■ Software escalable

## ■ Enfocar

## ■ Componentes de bajo coste

## ■ Hardware/Software accesible

# Objetivos

■ Material accesible.

■ Software ampliable y modificable.


■ Arquitectura de Sistema centralizado.

■ Sistema comunicación Wifi UDP.

■ Crear dos robots con distintos componentes.

■ Control movimiento de los robots.

# Software

■ TDD (Desarrollo guiado por pruebas)


■ Inyección de dependencias

■ Movimiento

■ Multihilo

■ Simulador

# TDD (Desarrollo guiado por pruebas)


# Inyección de Dependencias


## Diagrama de clases del Robot


# Movimiento


# Movimiento


# Movimiento


# Movimiento


# Movimiento


# Movimiento


# Multihilo


# Simulador


# Hardware


■ Microcontrolador
– ESP32 WROOM

■ Motores
– Corriente continua (CC / DC)
– Servos (rotación continua)


■ Circuitos integrados
– L293D para controlar los motores DC


■ Impresión 3D
– Creación del chasis
– Creación de las ruedas

■ Alimentación
– Batería powerbank 5V

# Microcontrolador (ESP32)


### ■ Wifi y Bluetooth

### ■ Bajo coste

### ■ Fácil de obtener

### ■ Compatibilidad con Arduino

# Motores

## Motor DC + L293D


### ■ 3 pines por motor

### ■ Control de velocidad más preciso

### ■ Circuito más complejo

## Motor Servo

### ■ 1 pin por motor

### ■ Control de velocidad menos preciso

■ Necesita modificación (https://learn.adafruit.com/modifying-servos-for-continuous-rotation/overview)

# Impresión 3D


Diseño | Impresión

# Resultado


# Presupuesto

Componente | Cantidad | Precio unitario | Total
ESP32-WROOM (https://es.aliexpress.com/item/1005002410521023.html?curPageLogUid=b8SKd9ntGUEf) | 1 | 3.57€ | 3.57€
IC L293D (https://es.aliexpress.com/item/32844099228.html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) | 1 | 0.22€ | 0.22€
Motor DC (https://es.aliexpress.com/item/1005002264331819.html?curPageLogUid=qrvC43PMpnFg) | 2 | 0.73€ | 1.46€
Powerbank (https://es.aliexpress.com/item/1005004227379153.html?curPageLogUid=xNM8dMRF95fI) | 1 | 1.29€ | 1.29€
Chasis (3D) | 1 | 1.00€ | 1.00€
Total | 7.54€
Componente | Cantidad | Precio unitario | Total
ESP32-WROOM (https://es.aliexpress.com/item/1005002410521023.html?curPageLogUid=b8SKd9ntGUEf) | 1 | 3.57€ | 3.57€
Motor servo (https://es.aliexpress.com/item/32944897962.html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) | 2 | 0.73€ | 1.46€
Powerbank (https://es.aliexpress.com/item/1005004227379153.html?curPageLogUid=xNM8dMRF95fI) | 1 | 1.29€ | 1.29€
Chasis (3D) | 1 | 1.00€ | 1.00€
Rueda (3D) | 2 | 1.48€ | 2.96€
Total | 12.00€
Robot con motores DC | Robot con motores Servo

# Líneas futuras

■ Software

– Aumentar la precisión del robot

– Algoritmo de Path Finding para evitar obstáculos

– Mapeado dinámico del área

– Simulador en Unity

■ Hardware

– Minimizar el tamaño del robot

– Utilizar drones

– Mejorar el consumo del robot

– Explorar otras formas de alimentación (energía solar, …)

– Pasar a una arquitectura jerárquica

Conclusiones; ■ Proyecto muy versátil; ■ Muchas utilidades; – Equipos de rescate; – Traslado de objetos; ■ Objetivos cumplidos; ■ Mejorable; ■ Alto potencial

– Trabajos en zonas desfavorables (mar, sitios estrechos, …)

# DEMO

# MINI SWARM ROBOTICS

Grado en Ingeniería Informática Trabajo Fin de Grado

Autor: Luis José Llamas Pérez

Director: Asier Ruperto Marzo Pérez
Co-Director: Josu Irisarri Erviti | Pamplona, 19/01/2023

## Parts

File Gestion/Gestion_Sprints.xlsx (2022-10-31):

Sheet: Resumen
Titulo del proyecto: |  |  | Inform Low-Cost
Miembros del equipo
Nombre | Rol | Responsabilidad
Luis | PO
Luis | Scrum Manager
Luis | Scrum Team
Sprints
Sprint | Fecha Prevista | Fecha Real | Velocidad | Meta | Conclusiones
Sprint 0 | 2022-07-14 |  |  | Seleccion del Hardware
Sprint 1 | 2022-07-31 |  |  | Realizar las librerías (Primera versión) para el control Hardware
Sprint 2 | 2022-08-14 |  |  | Realizar diseños 3D y corte de acrilico.
Sprint 3 | 2022-08-21 |  |  | Realizar primer montaje (Breadboard) y comprobar que todo funcione
Sprint 4 | 2022-08-25 |  |  | Realizar diseño PCBs
Sprint 5 | 2022-09-11 |  |  | Montaje de PCB
Sprint 6 | 2022-09-25 |  |  | Realizar Simulador en Unity
Sprint 7 | 2022-10-02 |  |  | Montar Red Neuronal para generar mapa de profundidades
Sprint 8 | 2022-10-16 |  |  | Prueba final / Corregir problemas
Descripción del contexto
Se quiere crear una versión de Inform pero "actualizada" a las tecnologías actuales y que sea de bajo coste. Dicho proyecto se va a componer de las siguientes partes (Sin ningún orden en concreto):
1- Hardware (MicroControlador, Motores, Shift Registers, Leds RGB, Controles Capacitivos)
2- Software (Control del Hardware, Simulador en Unity, Comunicación entre MCUs, CNN para dada una imagen, mover las columnas)
3- Diseño (Placa base, Conexionado para la Comunación entre MCUs/Simulador, Corte en Acrílico, Impresión 3D)
4- Montaje
5- Pruebas

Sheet: Backlog
ID | Nombre | Imp | Sprint | Estimado | Realizado | Estado | Notas
ID0001 | Determinar el tipo/modelo de motor a utilizar | 100 | 0 | 0.5 |  | Ok | Se ha decidido usar Steppers bi-polares, esto supone 4 conexiones por motor.
ID0002 | Determinar el tipo/modelo de Led RGB a utilizar | 100 | 0 | 0.5 |  | Ok | Se ha decidido utilizar WS2812b
ID0003 | Determinar el tipo/modelo de Micro Controlador a utilizar | 100 | 0 | 0.5 |  | Ok | Se ha decidido utilizar ESP32 VROOM
ID0004 | Determinar el tamaño de los modulos del proyecto | 100 | 0 | 0.5 |  | Ok | Se ha decidido utilizar tamaño de 4x4 columnas
ID0005 | Determinar el tipo/modelo de controlador capacitivo a utilizar | 90 | 0 | 0.5 |  | Ok
ID0006 | Determinar el tipo/modelo de Shift Registers | 95 | 0 | 0.5 |  | Ok | Debido al alto número de I/O necesario, se van a utilizar Shift Registers para ampliar el I/O del MCU. En concreto se van a usar 74hc595 (SIPO) y 74hc165 (PISO)

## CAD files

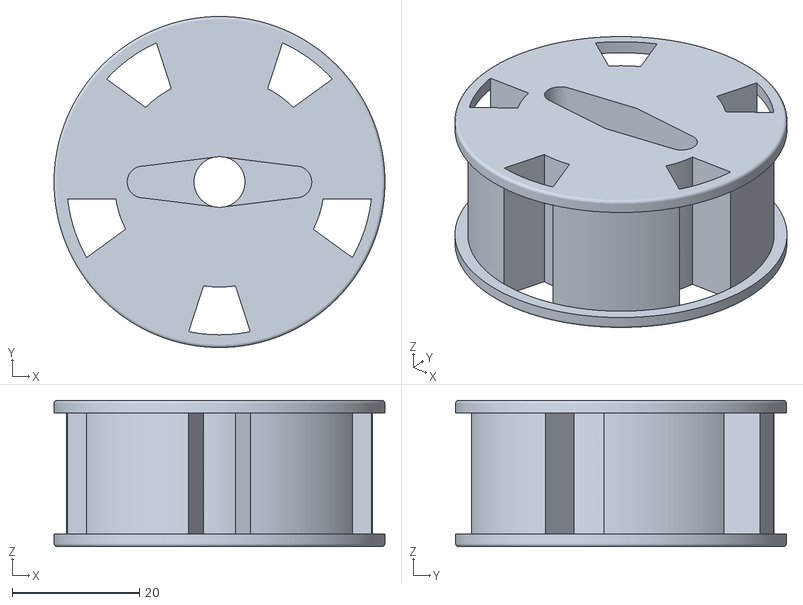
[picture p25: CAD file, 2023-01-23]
Memoria/rueda_servo_2.stl
52.0 x 52.0 x 23.0

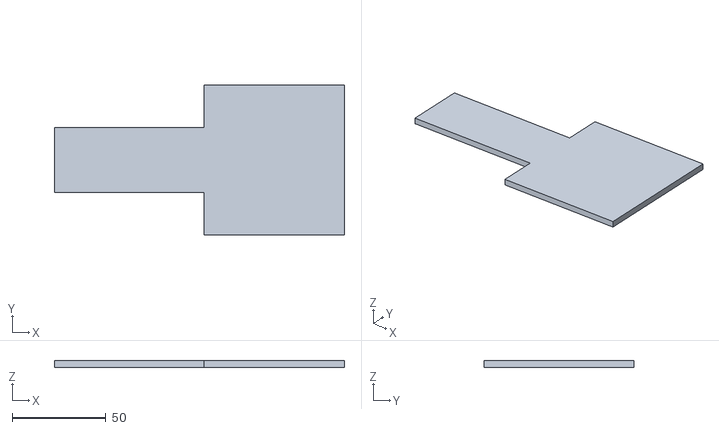
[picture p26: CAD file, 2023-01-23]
Memoria/chasis.stl
155.0 x 80.0 x 3.50

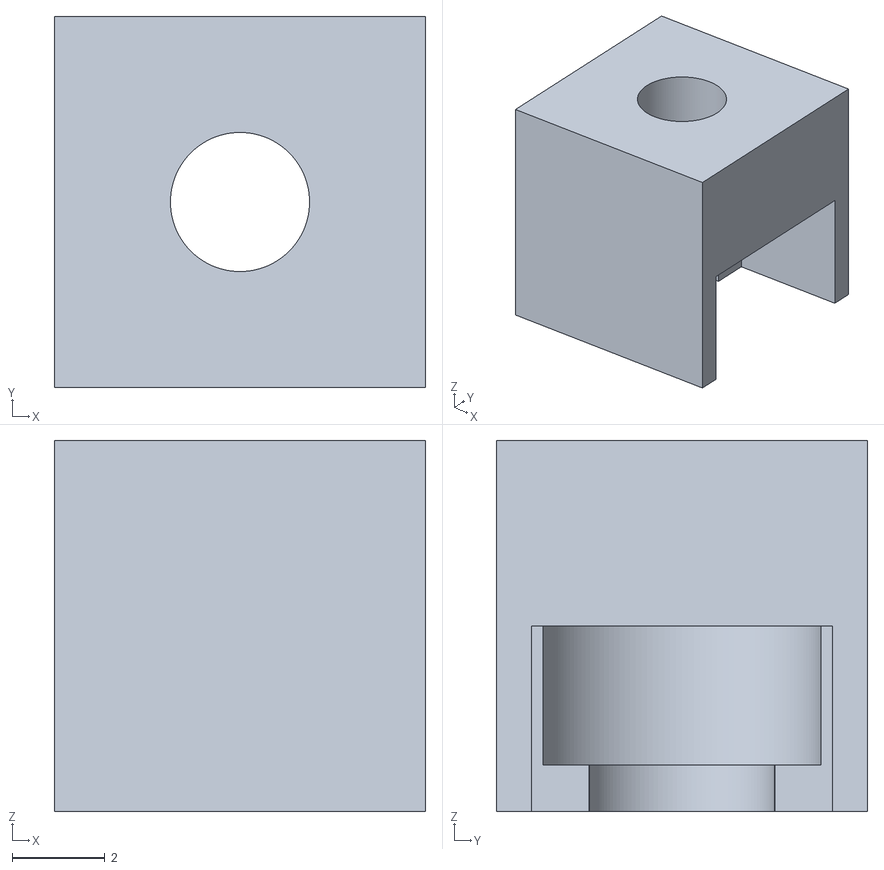
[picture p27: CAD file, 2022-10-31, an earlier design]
Modelos_3D/Antiguos/Adaptador_Tornillo_2.stl
8.00 x 8.00 x 8.00

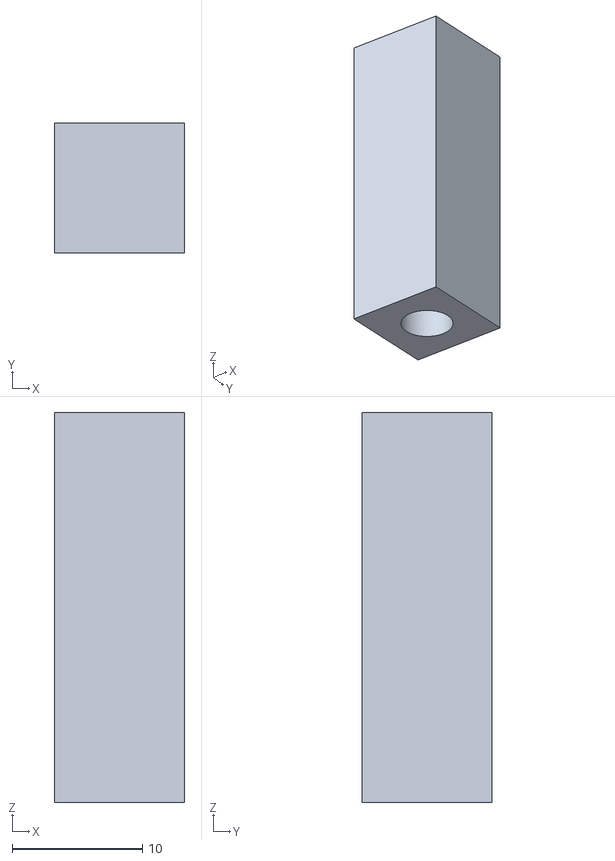
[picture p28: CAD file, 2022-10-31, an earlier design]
Modelos_3D/Antiguos/Columna_10_10.stl
10.0 x 10.0 x 30.0

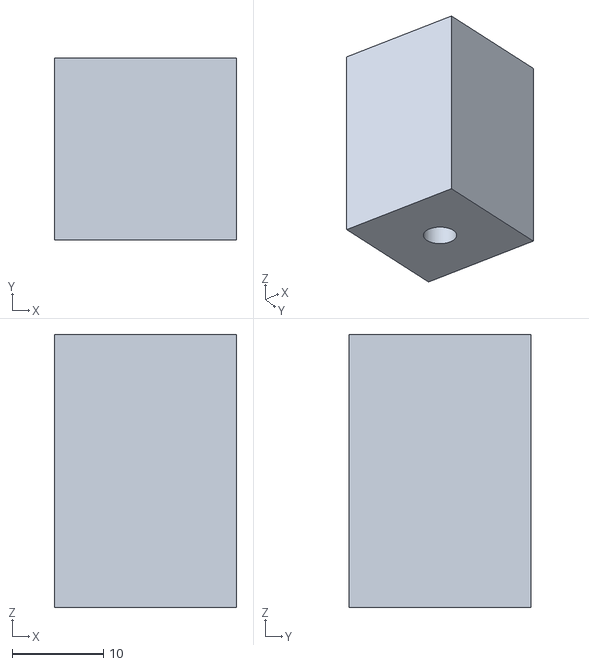
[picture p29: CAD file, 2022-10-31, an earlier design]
Modelos_3D/Antiguos/Columna_20_20.stl
20.0 x 20.0 x 30.0

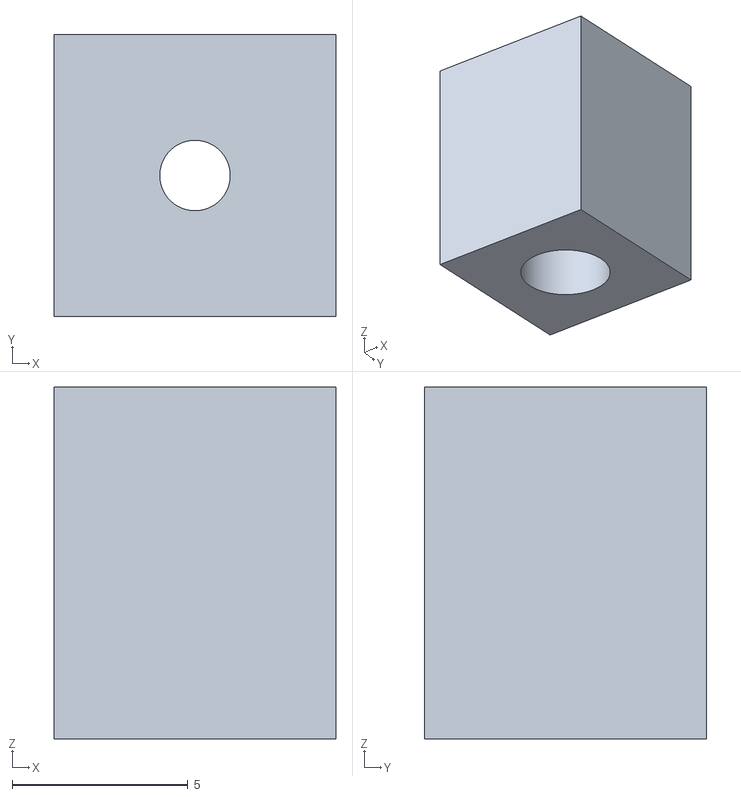
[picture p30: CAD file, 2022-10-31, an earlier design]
Modelos_3D/Antiguos/Adaptador_Tornillo.stl
8.00 x 8.00 x 10.0

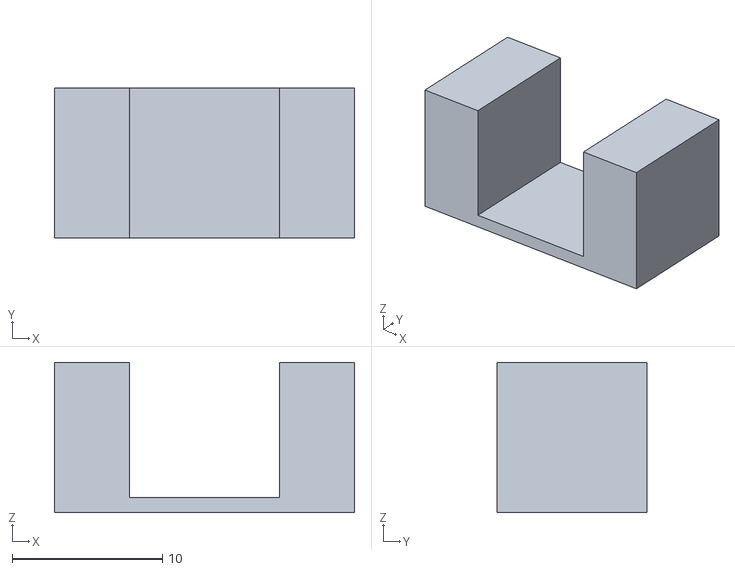
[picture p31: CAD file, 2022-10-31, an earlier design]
Modelos_3D/Antiguos/Soporte_Motor.stl
20.0 x 10.0 x 10.0

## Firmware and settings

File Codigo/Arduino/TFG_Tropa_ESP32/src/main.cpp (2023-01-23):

#include <UDPServer.hpp>
#include <CommandEnum.hpp>

#include "../lib/Led/Led/Led.hpp"
#include "../lib/Motor/Motor_DC/Motor_DC.hpp"
#include "../lib/Motor/Motor_Servo/Motor_Servo.hpp"
#include "../lib/Tropa/Tropa/Tropa.hpp"
#include "../lib/Communication/WifiClient/WifiClient.hpp"

// Declarations
void ProcessUDPPacket(AsyncUDPPacket packet); // Callback
void SerialCommand();                         // Callback

// Global Variables
// Primitive Types
String inString;
int command = -1;
int value = 0;

const char *ssid = "Bot-MindHive";
const char *pass = "LuisTFG2022";
const int port = 1234;
const uint8_t id = 2;
const char *hostname = "Tropa_2";

// Object Types
Led led = Led(2);

// Motor_DC motorIzq = Motor_DC(15,4,18); // D15, D4, D18 | EnableA, In1, In2
// Motor_DC motorDer = Motor_DC(32,12,33); // D35, D32, D12 | EnableB, In3, In4
Motor_Servo motorIzq = Motor_Servo(4, true);
Motor_Servo motorDer = Motor_Servo(12, true);
Tropa tropa = Tropa(id, led, motorIzq, motorDer);
WifiClient wifi = WifiClient(ssid, pass, hostname);
UDPServer udpServer = UDPServer(port, ProcessUDPPacket);

void setup()
{
  // tropa.Set_MaxMiddleMinSpeeds(192, 32, 0);
  tropa.Set_MaxMiddleMinSpeeds(16, 0, 0);

  motorIzq.setMaxSpeed(89);
  motorIzq.setMinSpeed(1);
  motorDer.setMaxSpeed(89);
  motorDer.setMinSpeed(1);
  motorIzq.setOffset(0);
  motorDer.setOffset(-9);
  motorIzq.Stop();
  motorDer.Stop();
  Serial.begin(115200);
  wifi.Start();
  udpServer.Start();
}

void loop()
{
  SerialCommand();
}

// Callback
void ProcessUDPPacket(AsyncUDPPacket packet)
{
  Serial.print("Command: ");
  CommandEnum command = static_cast<CommandEnum>(packet.data()[0]);
  switch (command)
  {
  case Forward:
    Serial.println("Move_Forward");
    tropa.Move_Forward();
  case Backwards:
    Serial.println("Move_Backward");
    tropa.Move_Backwards();
    break;
  case Turn_Left:
    Serial.println("Turn_Left");
    tropa.Turn_Left();
    break;
  case Turn_Right:
    Serial.println("Turn_Right");
    tropa.Turn_Right();
    break;
  case Change_Color:
    Serial.println("Change_Color");
    if (packet.length() < 4)
    {
      return;
    }
    tropa.Change_Color(packet.data()[1], packet.data()[2], packet.data()[3]);
    break;
  default:
    Serial.println("Not_Valid_Command");
  }
}

void ExecuteCommand()
{
  Serial.print("Command: ");
  Serial.print(command);
  Serial.print(" | Value: ");
  Serial.println(value);
  switch (command)
  {
  case Forward:
    Serial.println("Move_Forward");
    for (int i = 0; i < 20; i++)
      tropa.Move_Forward();
    break;
  case Backwards:
    Serial.println("Move_Backward");
    tropa.Move_Backwards();
    break;
  case Turn_Left:
    Serial.println("Turn_Left");
    tropa.Turn_Left();
    break;
  case Turn_Right:
    Serial.println("Turn_Right");
    tropa.Turn_Right();
    break;
  case 4:
    motorIzq.setOffset(value);
    break;
  case 5:
    motorDer.setOffset(value);
    break;
  case 6:
    motorIzq.ChangeSpeed(value);
    break;
  case 7:
    motorDer.ChangeSpeed(value);
    break;
  case 8:
    if (value > 0)
    {
      motorIzq.RotateLeft();
    }
    else
    {
      motorIzq.RotateRight();
    }
    break;
  case 9:
    if (value > 0)
    {
      motorDer.RotateLeft();
    }
    else
    {
      motorDer.RotateRight();
    }
    break;
  case 10:
    motorIzq.Stop();
    motorDer.Stop();
  case 11:
    motorIzq.setMaxSpeed(value);
    break;
  case 12:
    motorDer.setMaxSpeed(value);
    break;
  case 13:
    led.TurnOn();
    break;
  case 14:
    led.TurnOff();
    break;
  default:
    Serial.println("Not_Valid_Command");
  }

  command = -1;
  value = 0;
}

void SerialCommand()
{
  while (Serial.available())
  {
    char inChar = Serial.read();
    if (inChar == '\n')
    {
      value = inString.toInt();
      inString = "";
      ExecuteCommand();
    }
    else if ((inChar >= '0' && inChar <= '9') || (inChar == '+' || inChar == '-'))
    {
      inString += inChar;
    }
    else if (inChar == ' ')
    {
      command = inString.toInt();
      inString = "";
    }
  }
}

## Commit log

2022-07-11 Creación de la Memoria del TFG
2022-07-11 Creación de Excel (Gestión de Sprints)
    [Gestion_Sprints.xlsx]
2022-07-11 Actualización de Excel (Gestión de Sprints)
    [Gestion_Sprints.xlsx]
2022-10-31 Comenzada transición al nuevo proyecto
    Tras decidir que el Inform LowCost no iba a ser "impactante", se ha decidido cambiar el projecto a un MindHive con nombre aún pendiente por decidir.
    [Adaptador_Tornillo.stl, Adaptador_Tornillo_2.stl, Cmake_Config.txt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]
2022-11-01 [Código] Added Aruco and Leds classes (with its interfaces)
2022-11-06 Began Detecting Aruco in a Frame
2022-11-19 [CommandManager] Added filter and Queue for same type of commands
2022-11-21 Fixed angles+offsets, fakearucos always have to start at 0 degrees (unless you rotate the footprint aswell)
2022-12-01 [Arduino] Began with the Arduino Code
2022-12-02 [Arduino] Changed to Dependency Injection paradigm
2022-12-03 [Arduino] Software is done (all it's left is to finetune parameters)
    [Python] Created UDP Client
2023-01-01 [Memoria] Creados SVGs de explicación
2023-01-11 [Memoria] Corrección en el apartado Hardware - Sistema centralizado
2023-01-14 [Arduino] Added Servos
2023-01-15 [Memoria] revisión servos
2023-01-18 [Arduino | Python] Fixes
    [main.cpp]
2023-01-22 Added STLs
    [chasis.stl, rueda_servo_2.stl]
